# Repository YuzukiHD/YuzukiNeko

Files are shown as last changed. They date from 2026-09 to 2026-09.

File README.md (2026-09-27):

# YuzukiNeko Pico Development Board

> CC0-1.0 open-source hardware · Raspberry Pi Pico-style 2 × 20 pin layout · RISC-V multimedia SoC

<div align="center">
    3D_PCB1_2026-09
</div>

This compact development board is based on the **F101 Series SoC**. It follows the Raspberry Pi Pico form factor with two 20-pin rows, and includes 16 MiB of PSRAM (F101S3) or 32 MiB PSRAM (F101S4)  plus 16 MiB of NOR Flash with XIP (execute-in-place) support. It is a capable hardware platform for RISC-V graphics, display, audio, and general-purpose I/O projects.

> The *multiplexed functions* in this document are functions the SoC **can select** on a pin. They are not simultaneous functions, nor do they imply that every function is routed, enabled, or used by default on this board. Configure one function per pin in pinctrl/pinmux software.

## Board Features

| Item | Specification |
| --- | --- |
| SoC | F101S3 with XuanTie C907 RISC-V CPU, QFN68 (7 mm × 7 mm) |
| CPU cache | 32 KB I-cache + 16 KB D-cache |
| RAM | SiP 16-bit PSRAM, up to 16 MiB; 16 MiB fitted on this board |
| Storage | 16 MiB external NOR Flash with XIP support |
| Expansion headers | Pico-style 2 × 20 pin layout |
| USB | USB-C connector; the SoC provides one USB 2.0 DRD controller |
| Other visible hardware | microSD card socket and a button labelled `FEL` |
| Open-hardware license | [CC0 1.0 Universal](https://creativecommons.org/publicdomain/zero/1.0/) |

> The onboard NOR Flash are system resources.

## SoC Capabilities

| Block | Capability |
| --- | --- |
| Image decoding | JPEG up to 16384 × 16384; PNG up to 2048 × 2048 |
| Image/video encoding | JPEG/MJPEG up to 720p@30 fps; maximum resolution 8192 × 8192 |
| Display processing | de-interlace up to 720p@60 fps; G2D rotation and mixing accelerator |
| Video output | RGB888 up to 1280 × 720@60 fps; single-link LVDS up to 1366 × 768@60 fps; 4-lane MIPI DSI up to 1280 × 800@60 fps |
| Audio | One DAC (DACOUT), I2S/PCM, OWA OUT |
| Security | 512-bit eFuse |
| Connectivity and peripherals | USB 2.0 DRD × 1, SDIO 2.0, SPI × 2, UART × 6, TWI × 3, CAN × 2, PWM, IR_RX, GPADC, TPADC |

## Pinout

The view below is from the **component side with the USB-C connector at the top**. Rows progress from the USB-C end towards the microSD socket.

### V1.3 errata: PD pin-numbering error

F101S3 has no `PD10` or `PD11`. On the V1.3 PCB, the PD silkscreen was numbered consecutively after `PD9`; this makes every PD label from `PD10` onwards **two lower than the actual SoC GPIO number**. This is an identification error in the V1.3 silkscreen. V1.4 corrects the labels; use the **actual F101S3 GPIO / V1.4 silkscreen** column below for pinmux, software, and schematics.

| V1.3 silkscreen | Actual F101S3 GPIO / V1.4 silkscreen | Effect |
| --- | --- | --- |
| `PD10` | `PD12` | MUX selection must use `PD12` |
| `PD11` | `PD13` | MUX selection must use `PD13` |
| `PD12`–`PD20` | `PD14`–`PD22` | Each corresponding label is offset by +2 |

### V1.4 and earlier errata: microSD card-detect (CD) pull-down

The microSD card-detect (CD) signal is `PF6`, pulled down by `R11`. On V1.4 and earlier boards `R11` is **10 kΩ**. That value is too high for the pin to settle reliably below the logic-low threshold, so card insertion may not be detected. Until the hardware is changed, configure `PF6`'s **output drive strength to its lowest setting** in pinctrl. V1.5 changes `R11` to **1 kΩ**, which resolves the problem.

> **Which revision do I need?** If you only need the F101S3 with 16 MiB PSRAM, V1.4 is enough: replace `R11` with 1 kΩ and the card-detect problem is gone. V1.5 exists specifically for the 32 MiB PSRAM configuration, which requires the additional PSRAM LDO rail.

| Header row | Left: V1.3 silkscreen | Left: actual SoC GPIO / V1.4 silkscreen | Right: V1.3 silkscreen | Right: actual SoC GPIO / V1.4 silkscreen |
| ---: | --- | --- | --- | --- |
| 1 | `3V3` | `3V3` | `5V` | `5V` |
| 2 | `PD6` | `PD6` | `GND` | `GND` |
| 3 | `PD7` | `PD7` | `PD5` | `PD5` |
| 4 | `PD8` | `PD8` | `PD4` | `PD4` |
| 5 | `PD9` | `PD9` | `PD3` | `PD3` |
| 6 | `PD10` | **`PD12`** | `PD2` | `PD2` |
| 7 | `PD11` | **`PD13`** | `PD1` | `PD1` |
| 8 | `PD12` | **`PD14`** | `PD0` | `PD0` |
| 9 | `PD13` | **`PD15`** | `PD20` | **`PD22`** |
| 10 | `PD14` | **`PD16`** | `PB0` | `PB0` |
| 11 | `PD15` | **`PD17`** | `PB1` | `PB1` |
| 12 | `PD16` | **`PD18`** | `PB2` | `PB2` |
| 13 | `PD17` | **`PD19`** | `PB3` | `PB3` |
| 14 | `PD18` | **`PD20`** | `GPADC` | `GPADC` |
| 15 | `PD19` | **`PD21`** | `PE5` | `PE5` |
| 16 | `PE0` | `PE0` | `PE6` | `PE6` |
| 17 | `PE1` | `PE1` | `PE7` | `PE7` |
| 18 | `PE2` | `PE2` | `PE8` | `PE8` |
| 19 | `PE3` | `PE3` | `PE9` | `PE9` |
| 20 | `PE4` | `PE4` | `PE10` | `PE10` |

`3V3`, `5V`, and `GND` are power pins, not GPIO; design external interfaces for 3.3V logic. `GPADC` is the analog-input pin. Its exact channel, input range, and reference voltage must be confirmed from the schematic and SoC documentation.

## Pin Multiplexing (MUX)

Every GPIO in the following tables can be used as ordinary GPIO: **Function0 is input and Function1 is output**. Functions11–13 are reserved; **EINT is Function14**. `F<n>` below is the pinmux functions, sheet **2 GPIO Multiplex Function**. Functions in a single row are mutually exclusive.

### Left header — actual SoC GPIO

| Pin | Available alternate functions | EINT |
| --- | --- | --- |
| `PD6` | F2 LCD0-D10; F3 SPI1-CS1; F4 I2S0-MCLK; F5 UART4-TX; F6 PWM0-0 | F14 PD-EINT6 |
| `PD7` | F2 LCD0-D11; F3 IR-RX; F4 I2S0-BCLK; F5 UART4-RX; F6 PWM0-1 | F14 PD-EINT7 |
| `PD8` | F2 LCD0-D12; F3 TWI1-SCK; F4 I2S0-LRCK; F5 UART4-RTS; F6 PWM0-2 | F14 PD-EINT8 |
| `PD9` | F2 LCD0-D13; F3 TWI1-SDA; F4 I2S0-DOUT0; F5 UART4-CTS; F6 PWM0-3; F7 LCD0-VSYNC | F14 PD-EINT9 |
| `PD12` | F2 LCD0-D18; F3 LVDS0-D0P; F4 DSI-D0P; F5 UART3-RX; F6 TWI0-SDA | F14 PD-EINT12 |
| `PD13` | F2 LCD0-D19; F3 LVDS0-D0N; F4 DSI-D0N; F5 UART2-TX | F14 PD-EINT13 |
| `PD14` | F2 LCD0-D20; F3 LVDS0-D1P; F4 DSI-D1P; F5 UART2-RX | F14 PD-EINT14 |
| `PD15` | F2 LCD0-D21; F3 LVDS0-D1N; F4 DSI-D1N; F5 UART2-RTS | F14 PD-EINT15 |
| `PD16` | F2 LCD0-D22; F3 LVDS0-D2P; F4 DSI-CKP; F5 UART2-CTS | F14 PD-EINT16 |
| `PD17` | F2 LCD0-D23; F3 LVDS0-D2N; F4 DSI-CKN; F5 UART5-TX | F14 PD-EINT17 |
| `PD18` | F2 LCD0-CLK; F3 LVDS0-CKP; F4 DSI-D2P; F5 UART5-RX | F14 PD-EINT18 |
| `PD19` | F2 LCD0-HSYNC; F3 LVDS0-CKN; F4 DSI-D2N; F5 UART5-RTS; F6 UART4-TX | F14 PD-EINT19 |
| `PD20` | F2 LCD0-VSYNC; F3 LVDS0-D3P; F4 DSI-D3P; F5 UART5-CTS; F6 UART4-RX | F14 PD-EINT20 |
| `PD21` | F2 LCD0-DE; F3 LVDS0-D3N; F4 DSI-D3N; F5 UART1-TX; F6 UART4-RTS | F14 PD-EINT21 |
| `PE0` | F3 LCD0-D0; F4 TWI1-SCK; F5 I2S0-MCLK; F6 UART0-TX; F7 CAN0_TX0; F8 SPI1-CS0/DBI-CSX; F9 SDC2-D1; F10 CLK-FANOUT0 | F14 PE-EINT0 |
| `PE1` | F3 LCD0-D1; F4 TWI1-SDA; F5 I2S0-BCLK; F6 UART0-RX; F7 CAN0_RX0; F8 SPI1-CLK/DBI-SCLK; F9 SDC2-D0 | F14 PE-EINT1 |
| `PE2` | F3 LCD0-D8; F4 TWI0-SCK; F5 I2S0-LRCK; F6 UART4-TX; F7 CAN1_TX0; F8 SPI1-MOSI/DBI-SDO; F9 SDC2-CLK; F10 PWM0-0 | F14 PE-EINT2 |
| `PE3` | F3 LCD0-D9; F4 TWI0-SDA; F5 I2S0-DOUT0; F6 UART4-RX; F7 CAN1_RX0; F8 SPI1-MISO/DBI-SDI/DBI-TE/DBI-DCX; F9 SDC2-CMD; F10 PWM0-1 | F14 PE-EINT3 |
| `PE4` | F3 LCD0-D16; F4 TWI2-SCK; F5 I2S0-DIN0; F6 UART4-RTS; F7 UART5-TX; F8 SPI1-HOLD/DBI-DCX/DBI-WRX; F9 SDC2-D3; F10 PWM0-2 | F14 PE-EINT4 |

### Right header — actual SoC GPIO

| Pin | Available alternate functions | EINT |
| --- | --- | --- |
| `PD5` | F2 LCD0-D7; F3 SPI1-WP/DBI-TE; F4 UART2-CTS; F5 IR-RX; F6 TWI0-SDA | F14 PD-EINT5 |
| `PD4` | F2 LCD0-D6; F3 SPI1-HOLD/DBI-DCX/DBI-WRX; F4 UART2-RTS; F5 UART3-CTS; F6 TWI0-SCK | F14 PD-EINT4 |
| `PD3` | F2 LCD0-D5; F3 SPI1-MISO/DBI-SDI/DBI-TE/DBI-DCX; F4 UART2-RX; F5 UART3-RTS; F6 UART1-RX; F7 RJTAG-CK | F14 PD-EINT3 |
| `PD2` | F2 LCD0-D4; F3 SPI1-MOSI/DBI-SDO; F4 UART2-TX; F5 TWI0-SDA; F6 UART1-TX; F7 RJTAG-DO | F14 PD-EINT2 |
| `PD1` | F2 LCD0-D3; F3 SPI1-CLK/DBI-SCLK; F4 TWI1-SDA; F5 UART3-RX; F6 PWM0-0; F7 RJTAG-DI | F14 PD-EINT1 |
| `PD0` | F2 LCD0-D2; F3 SPI1-CS0/DBI-CSX; F4 TWI1-SCK; F5 UART3-TX; F6 TWI0-SCK; F7 RJTAG-MS | F14 PD-EINT0 |
| `PD22` | F2 OWA-OUT; F3 IR-RX; F4 PWM0-2; F5 UART1-RX; F6 UART4-CTS | F14 PD-EINT22 |
| `PB0` | F2 BOOST1-PWM; F3 TWI1-SCK; F4 UART1-TX; F5 UART2-RTS; F6 CAN1_TX0; F7 PWM0-0; F8 SPIF0-CS1 | F14 PB-EINT0 |
| `PB1` | F2 BOOST1-FB; F3 TWI1-SDA; F4 UART1-RX; F5 UART2-CTS; F6 CAN1_RX0; F7 PWM0-1; F8 IR-RX | F14 PB-EINT1 |
| `PB2` | F2 BOOST0-PWM; F3 TWI2-SCK; F4 UART1-RTS; F5 UART2-TX; F6 CAN0_TX0; F7 PWM0-2; F8 SPI0-CS1 | F14 PB-EINT2 |
| `PB3` | F2 BOOST0-FB; F3 TWI2-SDA; F4 UART1-CTS; F5 UART2-RX; F6 CAN0_RX0; F7 PWM0-3; F8 IR-RX | F14 PB-EINT3 |
| `GPADC` | Analog input (one-channel GPADC; board-level channel assignment needs schematic confirmation) | — |
| `PE5` | F3 LCD0-D17; F4 TWI2-SDA; F5 IR-RX; F6 UART4-CTS; F7 UART5-RX; F8 SPI1-WP/DBI-TE; F9 SDC2-D2; F10 PWM0-3 | F14 PE-EINT5 |
| `PE6` | F3 UART2-TX; F4 LCD0-D14; F5 CAN0_TX0; F6 OWA-OUT; F7 IR-RX; F8 SPI1-CS1 | F14 PE-EINT6 |
| `PE7` | F3 UART2-RX; F4 LCD0-D15; F5 CAN0_RX0; F8 SPI1-CS0/DBI-CSX; F9 CLK-FANOUT1 | F14 PE-EINT7 |
| `PE8` | F3 UART2-RTS; F4 TWI0-SCK; F5 CAN1_TX0; F6 UART3-TX; F7 PWM0-0; F8 SPI1-CLK/DBI-SCLK; F9 CLK-FANOUT2 | F14 PE-EINT8 |
| `PE9` | F3 UART2-CTS; F4 TWI0-SDA; F5 CAN1_RX0; F6 UART3-RX; F7 PWM0-1; F8 SPI1-MOSI/DBI-SDO | F14 PE-EINT9 |
| `PE10` | F3 UART4-TX; F4 TWI1-SCK; F5 I2S0-MCLK; F6 UART1-TX; F7 PWM0-2; F8 SPI1-MISO/DBI-SDI/DBI-TE/DBI-DCX | F14 PE-EINT10 |

## Common Peripheral Groups

This table is not a list of default board connections. It provides complete, typical combinations using exposed pins. Before selecting one, check for conflicts with enabled display, debug, power-management, or onboard peripherals.

| Purpose | One usable pin group | Notes |
| --- | --- | --- |
| UART0 | `PE0` F6 TX, `PE1` F6 RX | Basic serial-port pair |
| UART1 | `PB0` F4 TX, `PB1` F4 RX, `PB2` F4 RTS, `PB3` F4 CTS | UART1 signals can also be selected on other MUX groups |
| UART2 | `PD2` F4 TX, `PD3` F4 RX, `PD4` F4 RTS, `PD5` F4 CTS | `PE6` F3 / `PE7` F3 also provide TX / RX |
| UART3 | `PD0` F5 TX, `PD1` F5 RX, `PD3` F5 RTS, `PD4` F5 CTS | PE8 F6 / PE9 F6 and other pins offer alternate mappings |
| UART4 | `PD6` F5 TX, `PD7` F5 RX, `PD8` F5 RTS, `PD9` F5 CTS | `PE2`–`PE5` F6 provide corresponding alternate signals |
| UART5 | `PD17` F5 TX, `PD18` F5 RX, `PD19` F5 RTS, `PD20` F5 CTS | Avoids the lower-numbered PD pins |
| I²C / TWI0 | `PE2` F4 SCK, `PE3` F4 SDA | `PD0` F6 SCK + `PD2` F5 SDA and other mappings are also available |
| I²C / TWI1 | `PD8` F3 SCK, `PD9` F3 SDA | `PE0` F4 / `PE1` F4 may also be selected for TWI1 |
| I²C / TWI2 | `PB2` F3 SCK, `PB3` F3 SDA | `PE4` F4 / `PE5` F4 are alternate TWI2 pins |
| SPI1 | `PD0` F3 CS0, `PD1` F3 CLK, `PD2` F3 MOSI, `PD3` F3 MISO, `PD4` F3 HOLD, `PD5` F3 WP, `PD6` F3 CS1 | Usable as SPI or DBI; an alternate PE-pin group exists |
| I2S0 | `PD6` F4 MCLK, `PD7` F4 BCLK, `PD8` F4 LRCK, `PD9` F4 DOUT0; `PE4` F5 DIN0 | Use the signals needed for capture and/or playback |
| CAN0 | `PE0` F7 TX, `PE1` F7 RX | `PB2` F6 / `PB3` F6 and `PE6` F5 / `PE7` F5 are alternate pairs; requires an external transceiver |
| CAN1 | `PE2` F7 TX, `PE3` F7 RX | `PB0` F6 / `PB1` F6 and `PE8` F5 / `PE9` F5 are alternate pairs; requires an external transceiver |
| PWM0 | CH0: `PB0` F7 / `PD1` F6 / `PD6` F6 / `PE2` F10 / `PE8` F7; CH1: `PB1` F7 / `PD7` F6 / `PE3` F10 / `PE9` F7; CH2: `PB2` F7 / `PD8` F6 / `PE4` F10 / `PE10` F7; CH3: `PB3` F7 / `PD9` F6 / `PE5` F10 | Select one suitable MUX pin per channel |
| RGB / LVDS / DSI | Mainly `PD0`–`PD9` and `PD12`–`PD22`, plus selected PE pins | See the per-pin table for the exact F2–F7 selection. High-speed display signals require short, impedance-controlled routing and a suitable reference design |

## Notes and Safety

- A pin can select only one of GPIO, display, UART, SPI, TWI, and other functions at a time. Functions listed on the same row cannot be active together.
- Display, LVDS, MIPI DSI, USB, and XIP Flash are high-speed or boot-critical resources. Check the BSP pinctrl settings, device tree, and boot log before attaching expansion hardware.
- The CAN controllers expose logic-level signals only. A CAN transceiver and correct bus termination are required for a physical CAN bus.
- GPIO electrical limits, ADC range, output drive strength, and `FEL` download behavior must be confirmed by the complete F101S3 datasheet, schematic, and BSP. On a V1.3 board, always translate the affected PD silkscreen labels using the errata table before configuring pinmux; V1.4 silkscreen uses the corrected GPIO names.

## Revision History

| Revision | Changes |
| --- | --- |
| V1.5 | Added a dedicated PSRAM LDO rail, which enables the 32 MiB PSRAM configuration; this revision targets the 32 MiB build. microSD CD pull-down `R11` changed from 10 kΩ to 1 kΩ on `PF6` (see the V1.4-and-earlier errata above). |
| V1.4 | Corrected the PD silkscreen numbering; see the V1.3 errata table. For 16 MiB builds, V1.4 with `R11` changed to 1 kΩ is sufficient. |
| V1.3 | Initial release. |

## Contributing and License

The hardware design is dedicated to the public domain under [CC0 1.0](https://creativecommons.org/publicdomain/zero/1.0/). Contributions are welcome: schematics, PCB files, BOMs, BSP support, sample projects, errata, and verified pinout additions.

Unless stated otherwise, hardware design files in this repository are also released under CC0 1.0. Firmware, software, and third-party files follow the licenses specified in their respective directories.

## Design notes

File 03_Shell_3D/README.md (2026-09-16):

[Yuzuki Neko Case](YuzukiNeko_case.3mf), adapted from dj.santos' Pico case (BY-NC-SA).

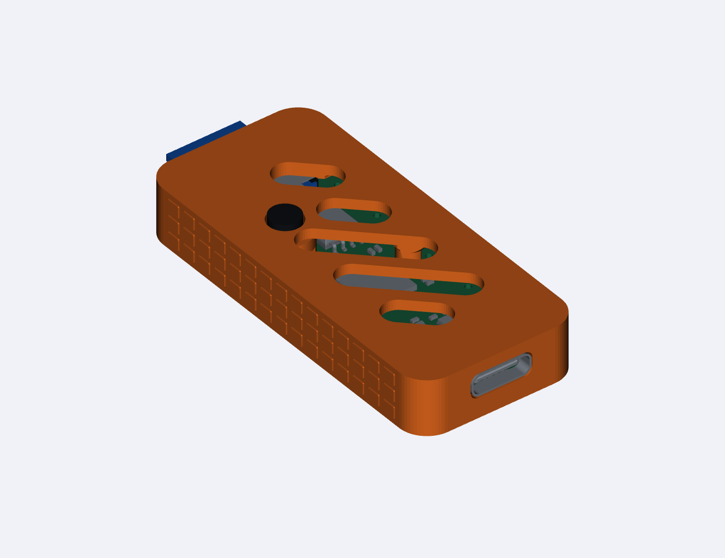
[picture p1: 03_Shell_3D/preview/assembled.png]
Assembled case, USB-C view


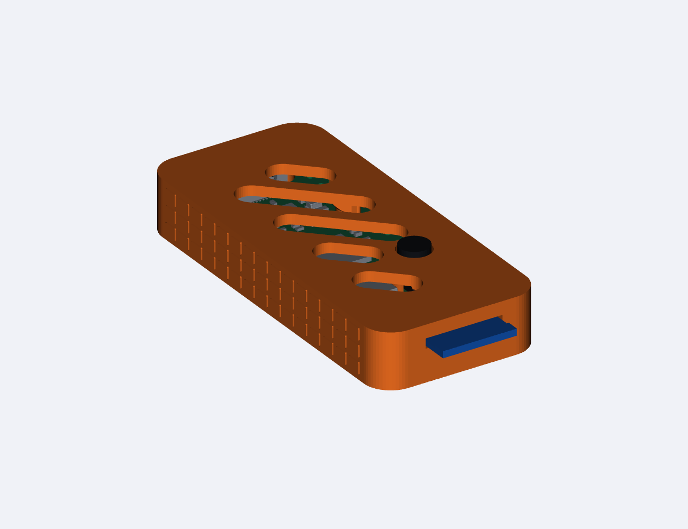
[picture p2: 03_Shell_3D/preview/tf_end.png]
Assembled case, microSD view


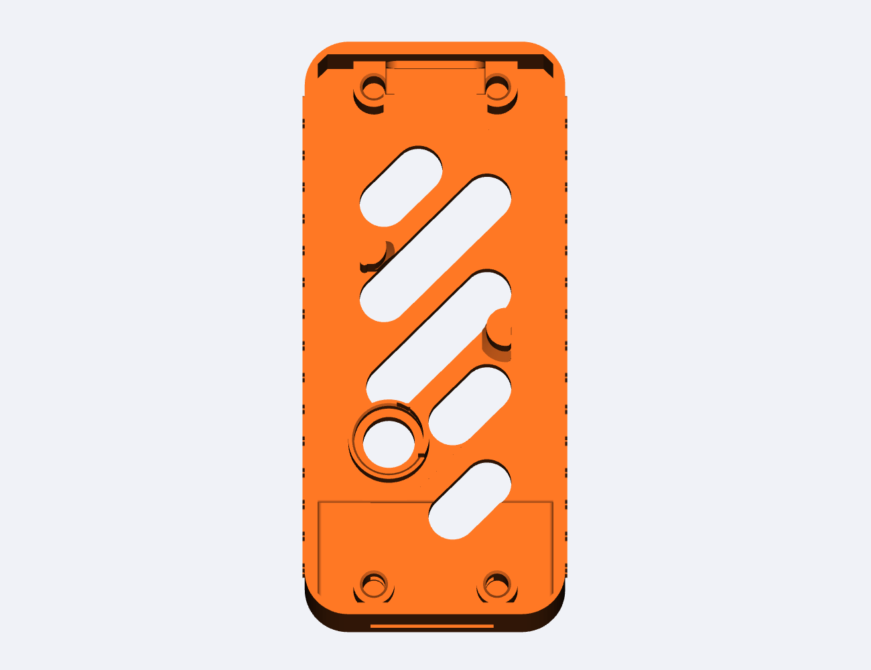
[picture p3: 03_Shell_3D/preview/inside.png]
Inside the upper shell


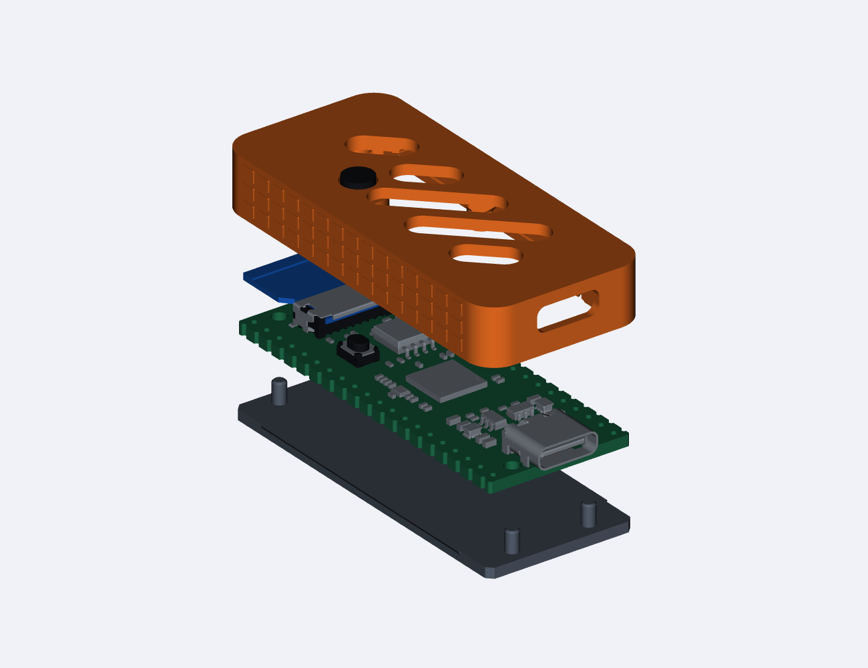
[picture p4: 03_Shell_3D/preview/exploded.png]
Exploded assembly


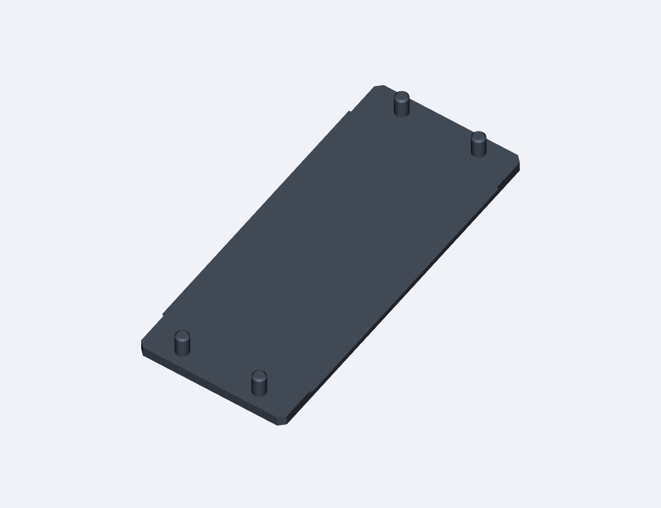
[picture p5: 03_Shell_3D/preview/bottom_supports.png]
Flat bottom shell with chamfered pin tips


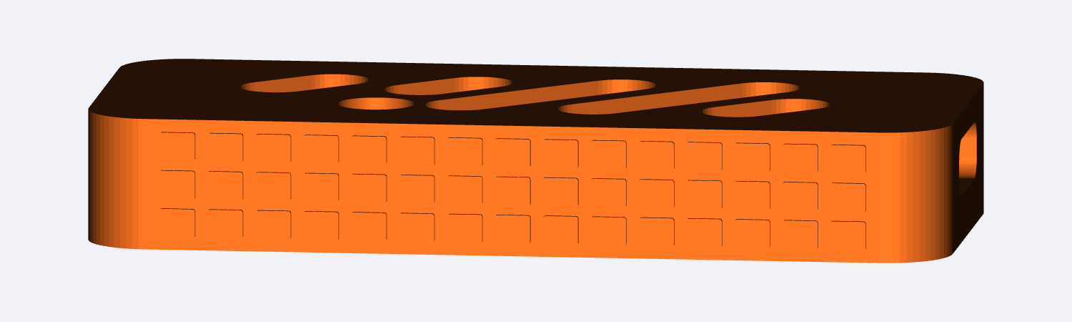
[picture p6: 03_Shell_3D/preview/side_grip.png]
Symmetric side grip


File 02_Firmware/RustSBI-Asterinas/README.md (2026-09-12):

# RustSBI + Asterinas for Yuzuki Neko

## Directory Overview

This directory provides SPI NOR boot images for the Yuzuki Neko **F101-S3**.
The boot sequence is SyterKit → RustSBI → Asterinas → BusyBox shell. These images
target the board tested with 16 MiB of PSRAM and 16 MiB of SPI NOR flash.

| File | Purpose | Size (bytes) |
| --- | --- | ---: |
| `syterkit-3bf4f61f.bin` | SyterKit with an eGON boot header; initializes PSRAM and loads subsequent images | 49,152 |
| `rustsbi-0.4.1.bin` | RustSBI 0.4.1, customized for Neko RV32 scalar extensions with WARN logging | 270,336 |
| `asterinas.bin` | Raw Asterinas RV32 kernel image | 2,762,160 |
| `yuzukineko-rustsbi-asterinas.img` | Full boot image containing the three components above, a device tree, and an initramfs with BusyBox | 7,143,424 |
| `SHA256SUMS` | SHA-256 checksums for the four images | — |
| `manifest.json` | Source versions, flash layout, and validation information | — |
| `licenses/` | Licenses & third-party notices | — |

See [manifest.json](manifest.json) for full version details.

Individual images use `.bin`, while the combined image uses `.img`. The `.img`
file contains **raw SPI NOR data** assembled at fixed offsets. It is neither a
PhoenixSuit container nor a disk image with a partition table.

## Flashing the Full Image

**Windows, Linux, and macOS are all supported as flashing hosts.** Install
**xfel or rfel** first, following the [Appendix](#appendix). The instructions
below assume that your chosen tool is on PATH and your terminal is in this directory.

Use the full image for the first installation or when switching from other
firmware. It writes to NOR addresses `0x000000..0x6d0000`; the range
`0x6d0000..0x1000000` is outside this write operation. “Full image” means that
the file contains everything needed to boot; it is not padded to the flash
chip's full 16 MiB capacity. To preserve the existing firmware, back it up first
as described in the Appendix.

1. Hold the board's **FEL** button, reconnect the USB data cable, then release the button.
2. Check the chip and flash using your chosen tool:

   ```sh
   xfel version
   xfel spinor
   ```

   Or:

   ```sh
   rfel version
   rfel spinor
   ```

   The tool should identify an F101 with chip ID `0x00193700` and 16 MiB of flash.
   If it reports `unsupported chip`, update to a version with F101 support.
   This operation does not require running the `ddr` command.

3. Choose one set of commands to write and read back the image:

   ```sh
   xfel spinor write 0x0 yuzukineko-rustsbi-asterinas.img
   xfel spinor read 0x0 0x6d0000 readback.img
   ```

   Or:

   ```sh
   rfel spinor write 0x0 yuzukineko-rustsbi-asterinas.img
   rfel spinor read 0x0 0x6d0000 readback.img
   ```

4. Calculate the SHA-256 checksums of the original image and `readback.img` as
   described in the Appendix. Confirm that they match each other and the entry
   in `SHA256SUMS`. Resolve any command errors or checksum mismatches before booting.
5. Release the FEL button and reset the board using your chosen tool:

   ```sh
   xfel reset
   ```

   Or:

   ```sh
   rfel reset
   ```

Connect a serial terminal to the board's UART using **115200 baud, 8N1, and no
flow control**. Booting opens a BusyBox shell. RustSBI uses WARN logging, so its
INFO banner is not displayed during normal boot.

## Replacing Individual Images

**Windows, Linux, and macOS are all supported.** Install **xfel or rfel** first
as described in the Appendix. The instructions below assume that the tool is
installed, your terminal is in this directory, and the board already has this
directory's full image installed. Reconnect USB while holding the FEL button,
then run your chosen tool's `version` and `spinor` commands to check the device.

Flash offsets differ from RAM load addresses in this layout. Use the
**NOR offsets** in the following table:

| Component | NOR offset | Reserved capacity in this layout | RAM load address |
| --- | --- | --- | --- |
| SyterKit | `0x000000` | 64 KiB | `0x00020000` |
| Device tree (included in the full image) | `0x010000` | 256 KiB | `0x40f40000` |
| RustSBI | `0x050000` | 512 KiB | `0x40f80000` |
| Asterinas | `0x0d0000` | 5 MiB, ending before the initramfs | `0x40000000` |
| initramfs (included in the full image) | `0x5d0000` | 1 MiB | `0x40500000` |

These capacity limits describe only this image's layout. Custom builds must
also keep entry points, load addresses, the device tree, and memory usage
compatible; binary size alone does not determine whether a replacement will
work. In particular, RustSBI's runtime memory, including BSS, stacks, and heap,
must fit within its reserved region.

Choose one or more write commands below as needed. Replacing one component does
not require writing the others.

**xfel:**

```sh
xfel spinor write 0x0 syterkit-3bf4f61f.bin
xfel spinor write 0x50000 rustsbi-0.4.1.bin
xfel spinor write 0xd0000 asterinas.bin
```

**rfel:**

```sh
rfel spinor write 0x0 syterkit-3bf4f61f.bin
rfel spinor write 0x50000 rustsbi-0.4.1.bin
rfel spinor write 0xd0000 asterinas.bin
```

After writing, read back the corresponding range using the actual file size
and verify it. For example, after replacing RustSBI with the file in this package:

```sh
xfel spinor read 0x50000 0x42000 rustsbi-readback.bin
```

The equivalent rfel command is:

```sh
rfel spinor read 0x50000 0x42000 rustsbi-readback.bin
```

`0x42000` is the size of this package's RustSBI file: 270,336 bytes. Adjust the
length to the actual file size for other versions. Once the readback SHA-256
matches the file you wrote, run `xfel reset` or `rfel reset`. Writing only the
three individual images does not install the device tree or root filesystem,
so use the full image for the first installation.

## Appendix

### Installing xfel

Obtain the tool from the [xboot/xfel repository](https://github.com/xboot/xfel).
This package was tested on the board using v1.3.6; your version must support F101.

**Windows**

Download `xfel-windows-v1.3.6.7z` from the repository's
[v1.3.6 release](https://github.com/xboot/xfel/releases/tag/v1.3.6), extract the
entire archive, add the directory containing `xfel.exe` to PATH, and reopen
PowerShell. Keep the bundled DLLs alongside the executable. If you do not set
PATH, you can run `./xfel.exe` from the tool's directory instead of `xfel`.

**Linux (Debian / Ubuntu example)**

Download the source from the repository, then build and install it:

```sh
sudo apt update
sudo apt install git build-essential pkg-config libusb-1.0-0-dev
git clone https://github.com/xboot/xfel.git
cd xfel
make
sudo make install
sudo udevadm control --reload-rules
```

Reconnect the FEL device so the installed udev rules take effect.

**macOS**

Install Xcode Command Line Tools and [Homebrew](https://brew.sh/), then obtain
the source from the repository:

```sh
xcode-select --install
brew install libusb pkg-config
git clone https://github.com/xboot/xfel.git
cd xfel
make
sudo install -m 755 xfel /usr/local/bin/xfel
```

If `/usr/local/bin` does not exist, first run `sudo mkdir -p /usr/local/bin`, and
ensure that the directory is on PATH. macOS does not use Linux udev rules.

### Installing rfel from Source

rfel is part of [rustsbi/allwinner-hal](https://github.com/rustsbi/allwinner-hal/tree/main/rfel).
Install [Rust and Cargo](https://www.rust-lang.org/tools/install), along with Git.
Windows also requires the C++ toolchain from Visual Studio Build Tools. Linux
requires a C compiler and linker (`build-essential` on Debian / Ubuntu), and
macOS requires Xcode Command Line Tools.

Run the following commands on any of the three host platforms:

```sh
git clone https://github.com/rustsbi/allwinner-hal.git
cd allwinner-hal
rustup update stable
cargo +stable install --path rfel
rfel --help
```

Use source containing `11544b3` (`feat(rfel): support F101 chip`) or subsequent
F101 support. If you have an older checkout, update the source before reinstalling.
Cargo usually installs executables to `%USERPROFILE%\.cargo\bin` on Windows or
`~/.cargo/bin` on Linux / macOS; ensure that this directory is on PATH.
`rfel version` queries the chip version of the connected device.

### USB Drivers and Access Permissions

If the tool cannot open the FEL device on Windows, use
[Zadig](https://zadig.akeo.ie/) to install the WinUSB driver for the
**FEL USB device (VID `1f3a`, PID `efe8`)**. Check the VID/PID before selecting
the device, and do not change the USB serial adapter's driver.

If rfel reports insufficient USB permissions on Linux, run the tool by its
absolute path with administrator privileges, or configure a udev rule for the
device. On desktop systems using systemd-logind, create
`/etc/udev/rules.d/70-allwinner-fel.rules` with the following contents:

```text
SUBSYSTEM=="usb", ATTR{idVendor}=="1f3a", ATTR{idProduct}=="efe8", TAG+="uaccess"
```

Run `sudo udevadm control --reload-rules`, then reconnect the device. On systems
without a desktop session, configure USB access according to the local user
groups. macOS does not require WinUSB or udev rules.

### Verifying Files

Windows PowerShell:

```powershell
Get-FileHash -Algorithm SHA256 yuzukineko-rustsbi-asterinas.img
Get-FileHash -Algorithm SHA256 readback.img
```

Linux:

```sh
sha256sum -c SHA256SUMS
sha256sum yuzukineko-rustsbi-asterinas.img readback.img
```

macOS:

```sh
shasum -a 256 -c SHA256SUMS
shasum -a 256 yuzukineko-rustsbi-asterinas.img readback.img
```

When replacing an individual image, substitute the corresponding original and
readback filenames in these commands.

### Backing Up the Existing Flash

After confirming that the board has 16 MiB of SPI NOR flash, run the following
in FEL mode:

```sh
xfel spinor read 0x0 0x1000000 neko-backup.bin
```

Or use:

```sh
rfel spinor read 0x0 0x1000000 neko-backup.bin
```

Keep your backup and its SHA-256 checksum, and do not overwrite an earlier
backup. To restore your own backup, use
`xfel spinor write 0x0 neko-backup.bin` or `rfel spinor write 0x0 neko-backup.bin`,
then read it back, verify it, and reset the board.

### Using the System After Boot

Run `/root/run-demos.sh` in the BusyBox shell to execute nine examples.
Serial input in this package is sensitive to long pasted strings; you can set
the terminal's transmit delay to approximately **20 ms per character**.
`reboot` restarts the system. `poweroff` stops the system, but the board remains
powered by USB; it does not cut the power supply.

### Licenses and Source Code

The firmware and its third-party software follow their respective licenses;
the CC0 declaration for hardware files does not apply to them. See
[licenses/README.md](licenses/README.md) for the license texts and provenance
of the four components currently retained.

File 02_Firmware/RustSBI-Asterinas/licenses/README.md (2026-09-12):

# Licenses and Provenance

This directory currently retains license texts and copyright notices in the
four component directories: `asterinas/`, `rustsbi/`, `busybox/`, and `syterkit/`.
Each component follows its own license. The hardware-oriented CC0 declaration
at the repository root does not cover this third-party firmware and software.

The retained license files come from the SyterKit / RustSBI source snapshots
used for the build, the Asterinas workspace, and the BusyBox 1.37.0 source code.
The original license texts are preserved.

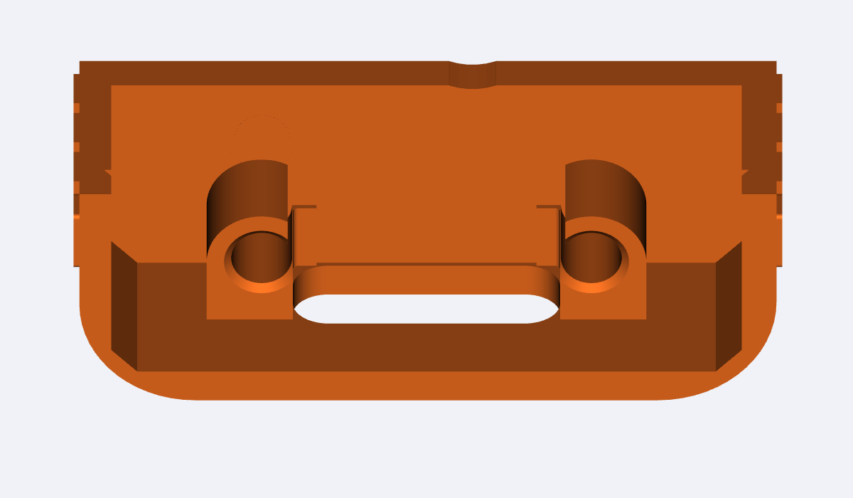
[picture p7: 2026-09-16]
03_Shell_3D/preview/usb_sockets.png

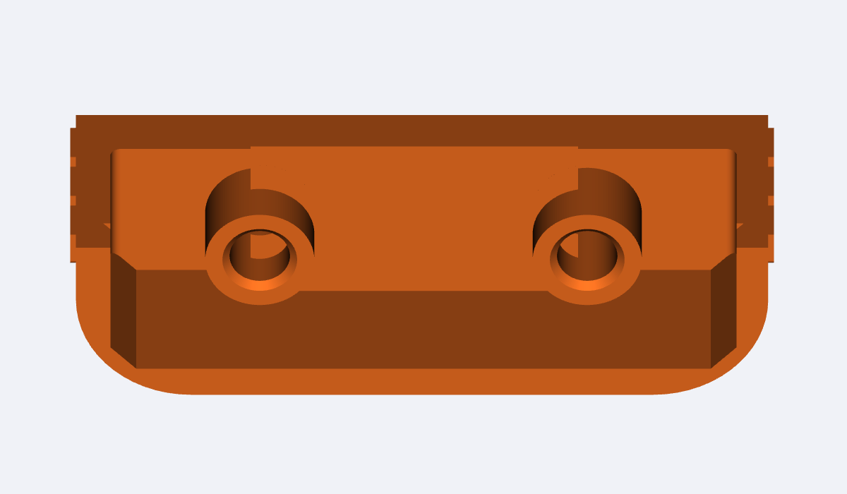
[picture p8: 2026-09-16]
03_Shell_3D/preview/tf_sockets.png

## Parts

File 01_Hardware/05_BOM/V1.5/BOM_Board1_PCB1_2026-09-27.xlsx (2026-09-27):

No. | Device | Name | Designator | Value | Footprint | Manufacturer | Manufacturer Part | Supplier | Supplier Part | Quantity | Pins | Category | Comment | LCSC Price
1 | 2.54PHSM-1X20P |  | H1,H2 |  | 2.54PHSM-1X20P | kinghelm(金航标) | KH-2.54PH180-1X16P-L11.5 | LCSC | C2905491 | 2 | 40 |  | KH-2.54PH180-1X16P-L11.5 | 0.83
2 | 0402CG220J500NT | 22pF | C20,C24 | 22pF | C0402-NSK | FH(风华) | 0402CG220J500NT | LCSC | C1555 | 2 | 2 | 电容:贴片电容(MLCC) | 22pF | 0.0256
3 | 0402WGF100KTCE | 1Ω | R9 | 1Ω | R0402-NSK | UNI-ROYAL(厚声) | 0402WGF100KTCE | LCSC | C25086 | 1 | 2 | 电阻:贴片电阻 | 1Ω | 0.0239
4 | 0402WGF330JTCE | 33Ω | R1,R2 | 33Ω | R0402-NSK | UNI-ROYAL(厚声) | 0402WGF330JTCE | LCSC | C25105 | 2 | 2 | 电阻:贴片电阻 | 33Ω | 0.0214
5 | 0402WGF1001TCE | 1kΩ | R11 | 1kΩ | R0402-NSK | UNI-ROYAL(厚声) | 0402WGF1001TCE | LCSC | C11702 | 1 | 2 | 电阻:贴片电阻 | 1kΩ | 0.011
6 | 0402WGF1002TCE | 10kΩ | R3,R8 | 10kΩ | R0402-NSK | UNI-ROYAL(厚声) | 0402WGF1002TCE | LCSC | C25744 | 2 | 2 | 电阻:贴片电阻 | 10kΩ | 0.0205
7 | 0402WGF1003TCE | 100kΩ | R4,R6,R7 | 100kΩ | R0402-NSK | UNI-ROYAL(厚声) | 0402WGF1003TCE | LCSC | C25741 | 3 | 2 | 电阻:贴片电阻 | 100kΩ | 0.0148
8 | 0402WGF5101TCE | 5.1kΩ | R10,R13,R15 | 5.1kΩ | R0402-NSK | UNI-ROYAL(厚声) | 0402WGF5101TCE | LCSC | C25905 | 3 | 2 | 电阻:贴片电阻 | 5.1kΩ | 0.0144
9 | CC0603KRX7R9BB104 | 100nF | C5,C18,C22 | 100nF | C0603-NSK | YAGEO(国巨) | CC0603KRX7R9BB104 | LCSC | C14663 | 3 | 2 | 电容:贴片电容(MLCC) | 100nF | 0.0751
10 | CKCS201610-2.2uH/M |  | L1,L2 | 2.2uH | IND-SMD_L2.0-W1.6_1 | CENKER(岑科) | CKCS201610-2.2uH/M | LCSC | C354533 | 2 | 2 |  | 2.2uH | 0.2145
11 | CL03A104KQ3NNNC | 100nF | C3 | 100nF | C0402-NSK | SAMSUNG(三星) | CL03A104KQ3NNNC | LCSC | C160831 | 1 | 2 | 电容:贴片电容(MLCC) | 100nF | 0.0266
12 | CL05A105KA5NQNC | 1uF | C11,C12,C25 | 1uF | C0402-NSK | SAMSUNG(三星) | CL05A105KA5NQNC | LCSC | C52923 | 3 | 2 | 电容:贴片电容(MLCC) | 1uF | 0.0605
13 | CL05A106MQ5NUNC | 10uF | C14 | 10uF | C0402-NSK | SAMSUNG(三星) | CL05A106MQ5NUNC | LCSC | C15525 | 1 | 2 | 电容:贴片电容(MLCC) | 10uF | 0.1572
14 | CL05A225MQ5NSNC | 2.2uF | C7,C8,C9,C10,C13 | 2.2uF | C0402-NSK | SAMSUNG(三星) | CL05A225MQ5NSNC | LCSC | C12530 | 5 | 2 | 电容:贴片电容(MLCC) | 2.2uF | 0.0325
15 | CL05B104KO5NNNC | 100nF | C1,C2,C15,C16,C17,C19,C26 | 100nF | C0402-NSK | SAMSUNG(三星) | CL05B104KO5NNNC | LCSC | C1525 | 7 | 2 | 电容:贴片电容(MLCC) | 100nF | 0.0274
16 | CL10A226MQ8NRNC | 22uF | C4,C6,C21,C23 | 22uF | C0603-NSK | SAMSUNG(三星) | CL10A226MQ8NRNC | LCSC | C59461 | 4 | 2 | 电容:贴片电容(MLCC) | 22uF | 0.1912
17 | F101 |  | U1 |  | QFN-68_L7.0-W7.0-P0.35-TL-EP4.5 |  |  |  |  | 1 | 69 |  | F101
18 | FRC0402F1503TS | 150kΩ | R14 | 150kΩ | R0402-NSK | FOJAN(富捷) | FRC0402F1503TS | LCSC | C2909320 | 1 | 2 | 电阻:贴片电阻 | 150kΩ | 0.0123
19 | FRC0402F6803TS | 680kΩ | R12 | 680kΩ | R0402-NSK | FOJAN(富捷) | FRC0402F6803TS | LCSC | C2909377 | 1 | 2 | 电阻:贴片电阻 | 680kΩ | 0.0103
20 | FRC0402J753 TS | 75kΩ | R5 | 75kΩ | R0402-NSK | FOJAN(富捷) | FRC0402J753 TS | LCSC | C2906965 | 1 | 2 | 电阻:贴片电阻 | 75kΩ | 0.0106
21 | KT-0603R | KT-0603R | LED1 |  | LED0603 NSK | KENTO | KT-0603R | LCSC | C2286 | 1 | 2 | 光电器件:发光二极管/LED | KT-0603R | 0.0461
22 | MT3520B |  | U7,U10 |  | SOT-23-5_L3.0-W1.7-P0.95-LS2.8-BR | 西安航天民芯 | MT3520B | LCSC | C2684933 | 2 | 5 |  | MT3520B
23 | MUP-M617-2 | MUP-M617-2 | U9 |  | TF-SMD_MUP-M617-2 | MUP(德海威) | MUP-M617-2 | LCSC | C5205359 | 1 | 12 | 连接器:SD卡连接器 | MUP-M617-2
24 | NCP114AMX280TCG | CJ6211B12F | U11 |  | UDFN-4_L1.0-W1.0-P0.65-BL-EP | CJ(江苏长电/长晶) | CJ6211B12F | LCSC | C2992031 | 1 | 5 | 电源芯片:线性稳压器(LDO) | CJ6211B12F
25 | PAD60 |  | U2,U3,U4,U5,U6 |  | PAD60 |  |  |  |  | 5 | 1 |  | PAD60
26 | PY25Q128HA-SUH-IT | PY25Q128HA-SUH-IT | U8 |  | SOP-8_L5.2-W5.3-P1.27-LS7.9-BL | PUYA(普冉) | PY25Q128HA-SUH-IT | LCSC | C7419750 | 1 | 8 | 存储器:NOR FLASH | PY25Q128HA-SUH-IT | 7.77
27 | TS3425BA | TS3425BA | SW1 |  | SW-SMD_4P-L4.2-W3.2-P2.15-LS4.6-1 | SHOU HAN(首韩) | TS3425BA | LCSC | C2681476 | 1 | 4 | 按键/开关:轻触开关 | TS3425BA | 0.2006
28 | TYPE-C 16PIN 2MD(073) | TYPE-C 16PIN 2MD(073) | USB1 |  | USB-C-SMD_TYPE-C-16PIN-2MD-073 | SHOU HAN(首韩) | TYPE-C 16PIN 2MD(073) | LCSC | C2765186 | 1 | 16 | 连接器:USB连接器 | TYPE-C 16PIN 2MD(073) | 0.4568
29 | XL7EL89CKI-111YLC-24M | 24MHz | X1 | 24MHz | osc-smd_4p-l2.0-w1.6-bl | YXC(扬兴晶振) | XL7EL89CKI-111YLC-24M | LCSC | C2965580 | 1 | 4 | 振荡器/谐振器:无源晶振 | 24MHz | 0.5002

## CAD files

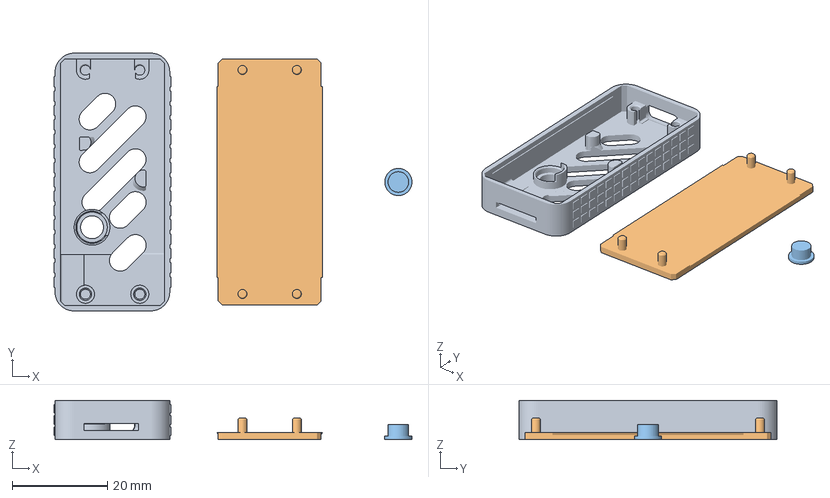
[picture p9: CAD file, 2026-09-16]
03_Shell_3D/YuzukiNeko_case.3mf
75.1 x 54.1 x 8.20 mm
YuzukiNeko_top
YuzukiNeko_bottom
YuzukiNeko_button

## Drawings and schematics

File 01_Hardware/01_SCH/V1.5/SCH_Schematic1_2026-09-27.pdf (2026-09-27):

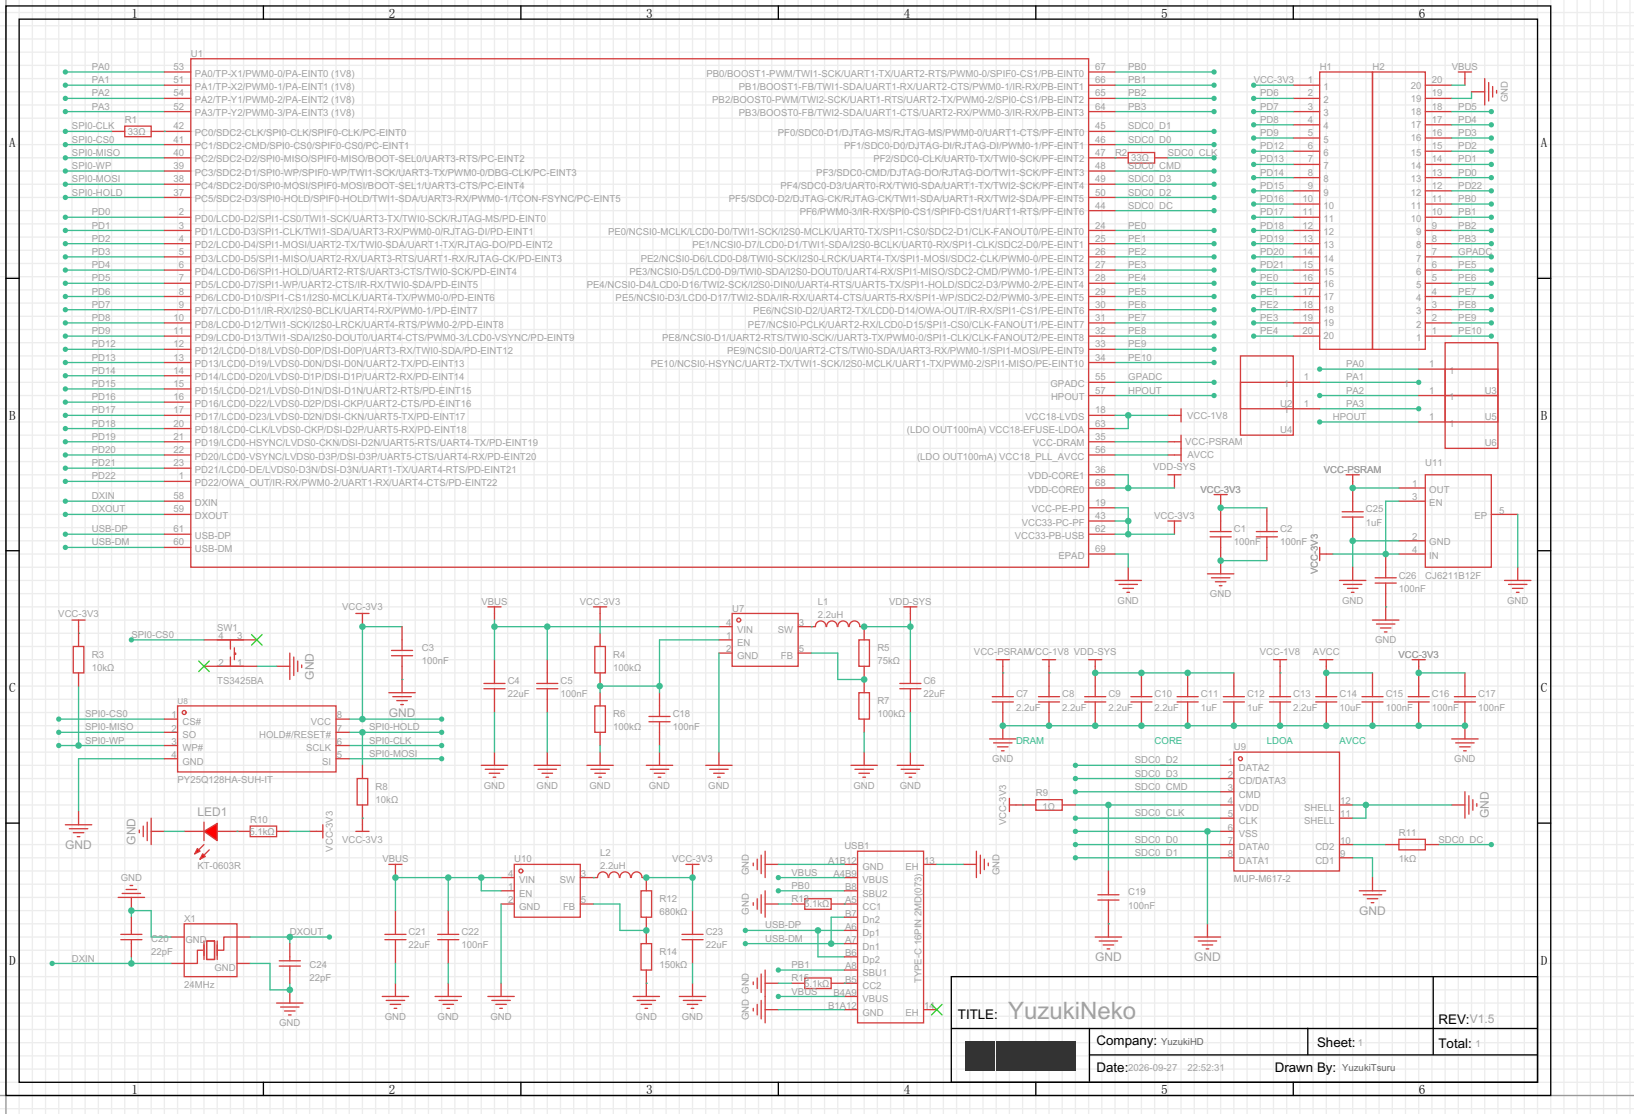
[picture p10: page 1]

PA0 | | | U1 | | | | | PB0 | | | | | H1 | | H2 | | | | VBUS
PA1 | | 53 | PA0/TP-X1/PWM0-0/PA-EINT0 (1V8) | | | | | PB1 | | VCC-3V3 | | 1

PA2 | | 51 | PA1/TP-X2/PWM0-1/PA-EINT1 (1V8) | PB3/BOOST0-FB/TWI2-SDA/UART1-CTS/UART2-RX/PWM0-3/IR-RX/PB-EINT3 | | 64 PB2/BOOST0-PWM/TWI2-SCK/UART1-RTS/UART2-TX/PWM0-2/SPI0-CS1/PB-EINT2 65 PB1/BOOST1-FB/TWI1-SDA/UART1-RX/UART2-CTS/PWM0-1/IR-RX/PB-EINT1 66 PB0/BOOST1-PWM/TWI1-SCK/UART1-TX/UART2-RTS/PWM0-0/SPIF0-CS1/PB-EINT0 67 | | PB2 | | | PD6 | 2 | | 1 | | 20 | | 20

54 | PA2/TP-Y1/PWM0-2/PA-EINT2 (1V8) | | | | | | | | | | | 2 | | 19 | | 19

PA3 | | 52 | PA3/TP-Y2/PWM0-3/PA-EINT3 (1V8) | | | | | PB3 | | | PD7 | 3 | | 3 | | 18 | | 18 | | PD5
SPI0-CLK | | R1 33Ω | | | | | | | SDC0_D1 | | | PD8 PD9 | 4 5 | | 4 | | 17 | | 17 | | PD4 PD3
SPI0-MISO | | | | PC5/SDC2-D3/SPI0-HOLD/SPIF0-HOLD/TWI1-SDA/UART3-RX/PWM0-1/TCON-FSYNC/PC-EINT5 37 PC4/SDC2-D0/SPI0-MOSI/SPIF0-MOSI/BOOT-SEL1/UART3-CTS/PC-EINT4 38 PC3/SDC2-D1/SPI0-WP/SPIF0-WP/TWI1-SCK/UART3-TX/PWM0-0/DBG-CLK/PC-EINT3 39 PC2/SDC2-D2/SPI0-MISO/SPIF0-MISO/BOOT-SEL0/UART3-RTS/PC-EINT2 40 PC1/SDC2-CMD/SPI0-CS0/SPIF0-CS0/PC-EINT1 41 PC0/SDC2-CLK/SPI0-CLK/SPIF0-CLK/PC-EINT0 42 | | PF6/PWM0-3/IR-RX/SPI0-CS1/SPIF0-CS1/UART1-RTS/PF-EINT6 | 44 PF5/SDC0-D2/DJTAG-CK/RJTAG-CK/TWI1-SDA/UART1-RX/TWI2-SDA/PF-EINT5 50 PF4/SDC0-D3/UART0-RX/TWI0-SDA/UART1-TX/TWI2-SCK/PF-EINT4 49 PF3/SDC0-CMD/DJTAG-DO/RJTAG-DO/TWI1-SCK/PF-EINT3 48 PF2/SDC0-CLK/UART0-TX/TWI0-SCK/PF-EINT2 47 PF1/SDC0-D0/DJTAG-DI/RJTAG-DI/PWM0-1/PF-EINT1 46 PF0/SDC0-D1/DJTAG-MS/RJTAG-MS/PWM0-0/UART1-CTS/PF-EINT0 45 | R2 | 33Ω | SDC0_CLK | | PD13 | 7 | | 6 | | 15 | | 15 | | PD1

A | SPI0-CS0 | | | | | | | | | SDC0_D0 | | | PD12 | 6 | | 5 | | 16 | | 16 | | PD2 | A

SPI0-WP | | | | | | | | | SDC0_CMD | | | | | | 7 | | 14 | | 14
SPI0-MOSI | | | | | | | | | SDC0_D3 | | | PD14 | 8 | | 8 | | 13 | | 13 | | PD0
SPI0-HOLD | | | | | | | | | SDC0_D2 | | | PD15 PD16 | 9 | | | | 12 | | 12 | | PD22 PB0
PD1 | | | PD0/LCD0-D2/SPI1-CS0/TWI1-SCK/UART3-TX/TWI0-SCK/RJTAG-MS/PD-EINT0 2 | | | | | PE0 | | | PD18 | | | 14 14 13 13 12 12 11 11 10 10 9 | | 10 | | 10 9 | | PB2
PD0 | | | | | | | | SDC0_DC | | | PD17 | | | | | 11 | | 11 | | PB1

PD1/LCD0-D3/SPI1-CLK/TWI1-SDA/UART3-RX/PWM0-0/RJTAG-DI/PD-EINT1 3 | | | | | | | | | | | | | | 9

PD2 | | | PD2/LCD0-D4/SPI1-MOSI/UART2-TX/TWI0-SDA/UART1-TX/RJTAG-DO/PD-EINT2 4 | | | | | PE1 | | | PD19 | | | | | | 8 | 8 | | PB3
PD3 PD4 | | | PD3/LCD0-D5/SPI1-MISO/UART2-RX/UART3-RTS/UART1-RX/RJTAG-CK/PD-EINT3 5 | | | | | PE2 PE3 | | | PD20 PD21 | | | | | | 7 | 7 6 | | GPADC PE5

PD4/LCD0-D6/SPI1-HOLD/UART2-RTS/UART3-CTS/TWI0-SCK/PD-EINT4 6

PD6 | PD5/LCD0-D7/SPI1-WP/UART2-CTS/IR-RX/TWI0-SDA/PD-EINT5 7 | | | | | | PE5 | | | | | PE1 | | | | 16 16 | | | 5 | 4 | | PE7

PD6/LCD0-D10/SPI1-CS1/I2S0-MCLK/UART4-TX/PWM0-0/PD-EINT6 8 | | | | | | | | | | | | | | | 17 17 | | | 4

PD7 | | | | | | | PE6 | | | | | PE2 | | | | 18 18 | | | 3 | 3 | | PE8
PD8 PD9 | | | | | | | PE7 PE8 | | | | | PE3 PE4 | | | | 19 19 | | | 2 | 2 1 | | PE9 PE10
PD12 | | | | | | | PE9 | | | | | | | | | 20 20 | | | 1

PD13 | | | | | | | PE10
PD14 | | | | | GPADC | 55 | GPADC | | | | | | | | 1 | | PA1 | | | | 1
PD15 PD16 | | | | | HPOUT | 57 | HPOUT | | | | | | | 1 | | | PA2 | | | 1 | 1 | | | U3
PD17 | | | | | | | | | | | | | U2 | 1 | 1 | | PA3

B | PD18 | | | VCC18-LVDS | | | 18 | | | VCC-1V8 | | | | | | | HPOUT | | | | 1 | 1 | | | U5 | | B

VCC-DRAM | | 35 (LDO OUT100mA) VCC18-EFUSE-LDOA 63 | | | | | | | U4

PD19 | | | | | | | | | VCC-PSRAM | | | | | | | | | | | | | | | U6
PD20 PD21 | | (LDO OUT100mA) VCC18_PLL_AVCC | | | | 56 | | | AVCC | | | | | | | | | | U11
PD22 | | | VDD-CORE1 | | | 36 | | VDD-SYS | | | | | | | | VCC-PSRAM

PD22/OWA_OUT/IR-RX/PWM0-2/UART1-RX/UART4-CTS/PD-EINT22 1 | | VDD-CORE0 | | | 68 | | | | VCC-3V3 | | | | | | | | | | OUT 1

DXIN | | | | | | | | | | | | | | | | | | | | EN 3
USB-DP | | | VCC33-PC-PF | | | 43 | | VCC-3V3 | | | C1 | C2 | | | | | | 1uF

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

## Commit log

2026-09-04 init for open source
    [BOM_Board1_PCB1_2026-09-04.xlsx, BOM_Board1_V1.3_PCB1_2026-09-04.xlsx, PickAndPlace_PCB1_2026_09_04.xlsx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]
2026-09-04 add missing bom
2026-09-12 feat(firmware): add RustSBI and Asterinas boot images
    Add SyterKit, RustSBI 0.4.1 and Asterinas binaries for Yuzuki Neko,
    along with a combined SPI NOR image, checksums and license notices.
    Document xfel and rfel installation, full-image flashing and
    individual component replacement.
2026-09-16 feat: add 3D printed shell
    Add a printable Yuzuki Neko case with USB-C, FEL button and microSD
    access, adapted from dj.santos' Pico case. Include a short README
    with assembly, interior and exploded previews.
    [YuzukiNeko_case.3mf]
2026-09-27 feat(hardware): add V1.5 release files and document V1.5 changes
    V1.5 adds a dedicated PSRAM LDO rail to support the 32 MiB PSRAM
    configuration, and changes the microSD card-detect pull-down R11 on
    PF6 from 10 kOhm to 1 kOhm.
    Document both in the README: add the V1.4-and-earlier card-detect
    errata, a revision history section, and a note that a 16 MiB build
    can stay on V1.4 by replacing R11.
    [BOM_Board1_PCB1_2026-09-27.xlsx, PickAndPlace_PCB1_2026_09_27.xlsx]
